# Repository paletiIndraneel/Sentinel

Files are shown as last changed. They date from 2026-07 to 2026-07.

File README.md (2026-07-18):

# Sentinel v1.0 firmware

Sentinel continuously monitors three-phase AC voltage and true internet
availability. It is an ESP32-S3 PlatformIO/Arduino project designed for the
provided controller PCB: ADS1115, DS3231, 128x64 SSD1306 OLED, microSD, and an
optional SHT31.

## Features

- 1-second RMS windows for R, Y, and B phase measurements
- Phase loss, under-voltage, over-voltage, and phase-imbalance events
- Internet reachability test using asynchronous TCP to a public endpoint
- Automatic Wi-Fi recovery without blocking `loop()`
- DS3231 ISO-8601 timestamps
- `events.csv` and `readings.csv` on a FAT32 microSD card
- OLED current voltage, connectivity, and fault status

## Project layout

```text
include/    Public module interfaces and configuration
src/        Module implementations and application composition root
lib/        Reserved for local libraries
docs/       Reserved for commissioning and operating documentation
hardware/   Reserved for released hardware assets
```

## Configure and flash

1. Install PlatformIO and open this directory.
2. Set `WIFI_SSID` and `WIFI_PASSWORD` in [include/config.h](include/config.h).
3. Verify `PHASE_SCALE`, phase-loss, under/over-voltage and imbalance limits
   against the installation requirements. Each ZMPT101B channel must be
   calibrated with an isolated, trusted reference meter.
4. Insert a FAT32 microSD card and upload:

   ```powershell
   pio run --target upload
   pio device monitor --baud 115200
   ```

## Connectivity behavior

The device distinguishes internet availability from mere association with a
Wi-Fi access point. It makes a non-blocking HTTP request to `1.1.1.1` every
minute. A 2xx response marks the internet `ONLINE`; connection failure or a
timeout marks it `OFFLINE`. Wi-Fi retry timing and endpoint configuration are
in `config.h`. No router monitoring, cloud connection, MQTT, OTA, dashboard,
or mobile functionality is included.

## Pin map

| Function | ESP32-S3 GPIO |
| --- | ---: |
| Status LED / Wi-Fi LED | 4 / 5 |
| I2C SDA / SCL | 8 / 9 |
| microSD CS / MOSI / SCK / MISO | 10 / 11 / 12 / 13 |

## Safety

This product interfaces with mains voltage. Commission only with suitable
isolation, enclosure, fusing and a qualified person. Default calibration is
`1.0` and is not a valid mains-voltage reading.

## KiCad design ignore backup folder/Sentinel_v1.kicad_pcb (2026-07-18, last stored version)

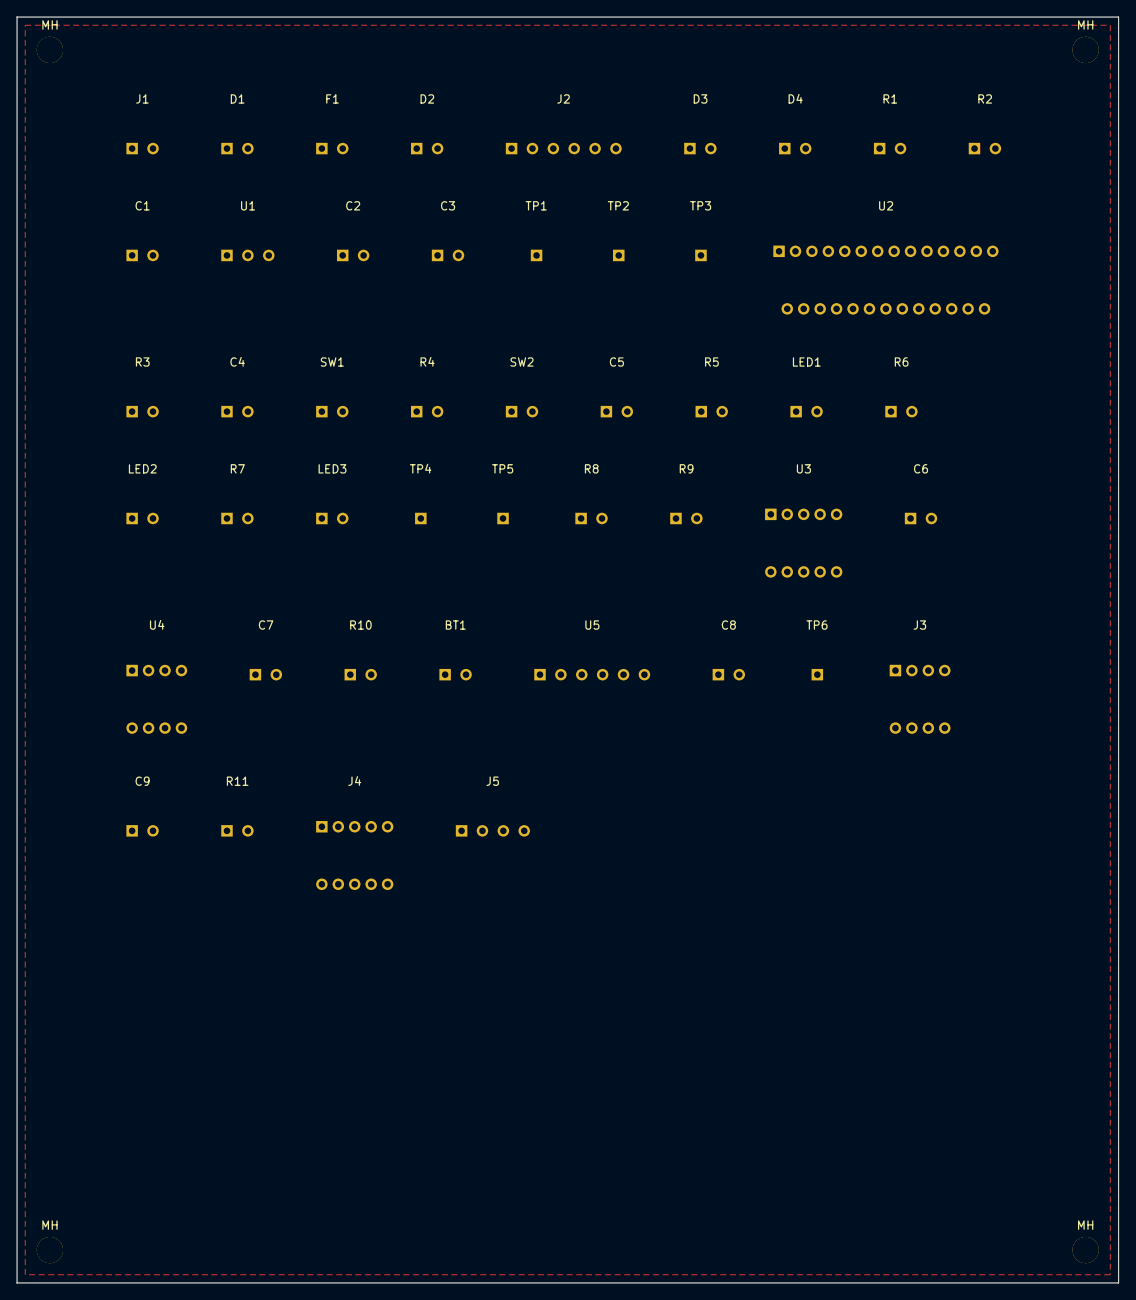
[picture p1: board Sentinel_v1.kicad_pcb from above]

Board: 2 copper layers, 134.0 x 154.0 mm, 51 parts (0 on the bottom side), 38 nets, no tracks yet.

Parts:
BT1: CR2032; BatteryHolder_Keystone_3034_1x20mm
C1, C2: 10uF; C_0603_1608Metric
C3, C4: 1uF; C_0603_1608Metric
C5, C6, C7, C8, C9: 0.1uF; C_0603_1608Metric
D1, D2, D3: SS34; D_SOD-123
D4: SMBJ5.0A; D_SOD-123
F1: MF-R500; Fuse_1210_3225Metric
J1: 5V_UPS_IN; TerminalBlock_bornier-2_P5.08mm
J2: USB-C; USB_C_Receptacle_HRO_TYPE-C-31-M-12
J3: MicroSD; microSD_HC_Molex-104031-0811
J4: EXP_HDR; PinHeader_2x05_P2.54mm_Vertical
J5: J_SENSOR; JST_XH_B4B-XH-A_1x04_P2.50mm_Vertical
LED1: STATUS; LED_0603_1608Metric
LED2: WIFI; LED_0603_1608Metric
LED3: PWR; LED_0603_1608Metric
MH: M3; MountingHole_3.2mm_M3
MH#2, MH#3, MH#4: M3; MountingHole_3.2mm_M3
R1, R2: 5.1k; R_0603_1608Metric
R3, R4, R10, R11: 10k; R_0603_1608Metric
R5, R6, R7: 330R; R_0603_1608Metric
R8, R9: 4.7k; R_0603_1608Metric
SW1: SW_RESET; SW_SPST_TL3342
SW2: SW_BOOT; SW_SPST_TL3342
TP1: TP_5V; TestPoint_Pad_1.5x1.5mm
TP2: TP_3V3; TestPoint_Pad_1.5x1.5mm
TP3: TP_GND; TestPoint_Pad_1.5x1.5mm
TP4: TP_SDA; TestPoint_Pad_1.5x1.5mm
TP5: TP_SCL; TestPoint_Pad_1.5x1.5mm
TP6: TP_A3_RSV; TestPoint_Pad_1.5x1.5mm
U1: AMS1117-3.3; SOT-223-3_TabPin2
U2: ESP32-S3-WROOM-1; ESP32-S2-MINI-1
U3: ADS1115; MSOP-10_3x3mm_P0.5mm
U4: DS3231; SOIC-16W_7.5x10.3mm_P1.27mm
U5: SHT31; DFN-8-1EP_2.5x2.5mm_P0.5mm_EP1.2x1.6mm

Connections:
3V3: C2.1, C3.1, C5.1, C6.1, C7.1, C8.1, C9.1, J3.3, J4.1, R3.1, R4.1, R7.1, R8.1, R9.1, R10.1, R11.1, TP2.1, U1.3, U2.1, U3.1, U4.1, U5.1
5V_A: D2.1, F1.2
5V_UPS_IN: D1.1, J1.1
5V_UPS_PROT: D1.2, F1.1
ADC_A3_RSV: TP6.1, U3.10
ADS_ALRT: U2.7, U3.6
BOOT: R4.2, SW2.1, U2.4
EN: C4.1, R3.2, SW1.1, U2.3
EXP_IO15: J4.3, U2.18
EXP_IO16: J4.4, U2.19
EXP_IO17: J4.5, U2.20
EXP_IO18: J4.6, U2.21
EXP_IO21: J4.7, U2.22
EXP_IO47: J4.8, U2.23
EXP_IO48: J4.9, U2.24
GND: BT1.2, C1.2, C2.2, C3.2, C4.2, C5.2, C6.2, C7.2, C8.2, C9.2, D4.2, J1.2, J2.2, J3.5, J3.8, J4.2, J4.10, J5.4, LED1.2, LED2.2, LED3.2, R1.2, R2.2, SW1.2, SW2.2, TP3.1, U1.2, U2.2, U2.25, U2.26, U2.27, U3.2, U3.5, U4.2, U5.2, U5.5
PHASE_B_ADC: J5.3, U3.9
PHASE_R_ADC: J5.1, U3.7
PHASE_Y_ADC: J5.2, U3.8
PWR_LED_A: LED3.1, R7.2
RTC_RST: R10.2, U4.7
SCL: R9.2, TP5.1, U2.9, U3.3, U4.4, U5.4
SDA: R8.2, TP4.1, U2.8, U3.4, U4.3, U5.3
SD_CS: J3.1, R11.2, U2.10
SD_MISO: J3.6, U2.13
SD_MOSI: J3.2, U2.11
SD_SCK: J3.4, U2.12
STATUS_GPIO: R5.1, U2.5
STATUS_LED_A: LED1.1, R5.2
USB_CC1: J2.5, R1.1
USB_CC2: J2.6, R2.1
USB_DM: J2.4, U2.14
USB_DP: J2.3, U2.15
VBAT: BT1.1, U4.8
VBUS_USB: D3.1, J2.1
VCC_5V: C1.1, D2.2, D3.2, D4.1, TP1.1, U1.1
WIFI_GPIO: R6.1, U2.6
WIFI_LED_A: LED2.1, R6.2

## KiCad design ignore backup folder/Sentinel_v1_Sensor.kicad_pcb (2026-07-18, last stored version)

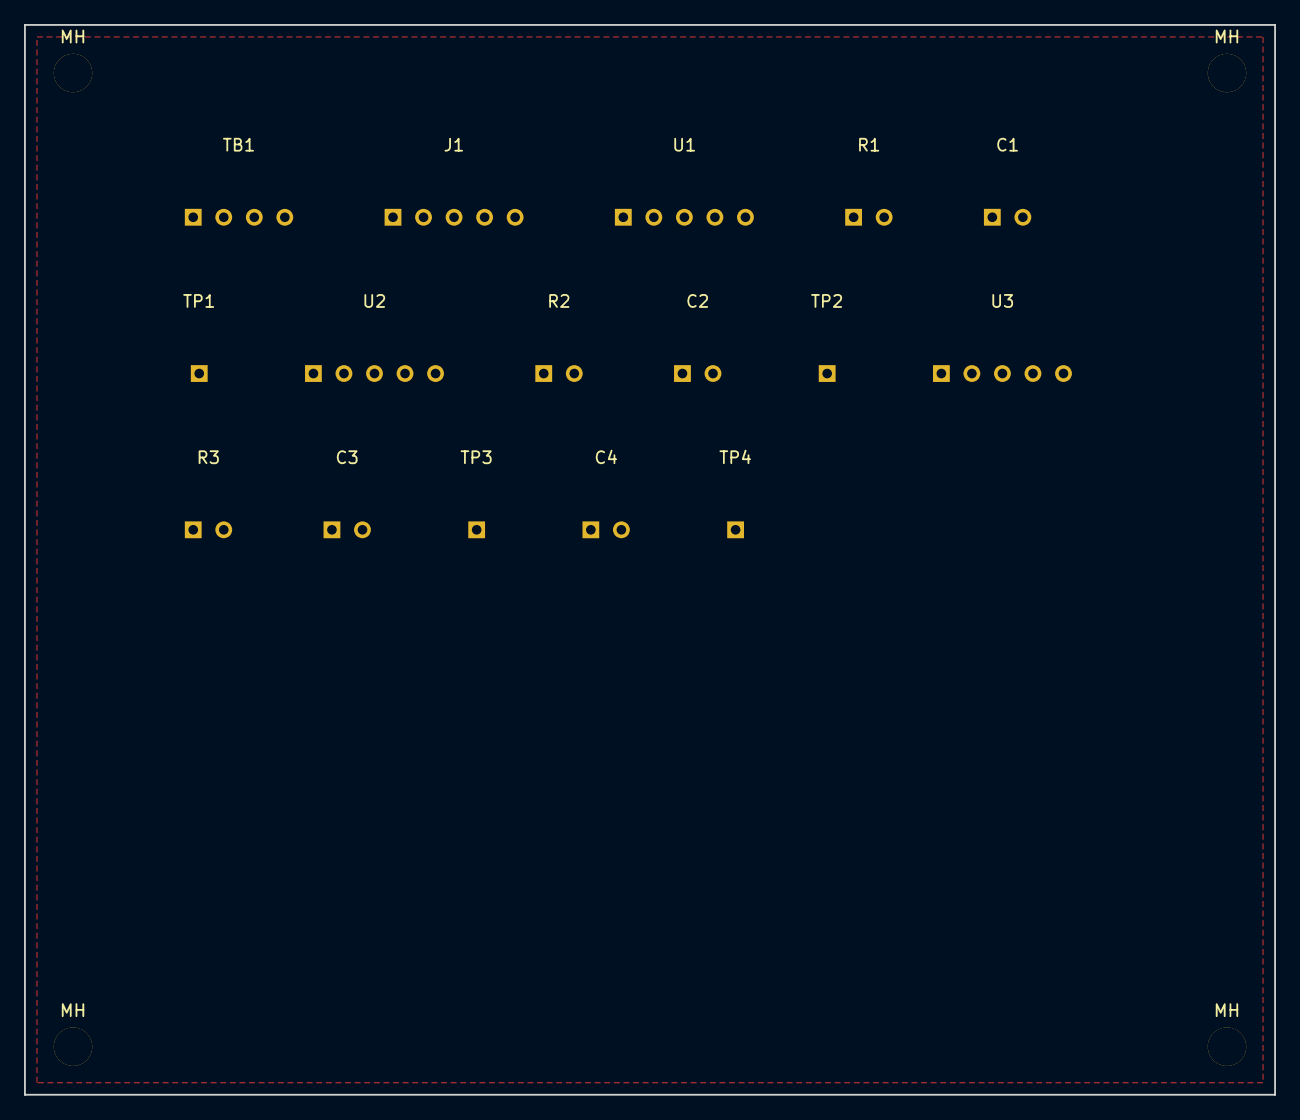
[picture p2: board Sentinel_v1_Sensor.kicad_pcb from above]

Board: 2 copper layers, 104.0 x 89.0 mm, 20 parts (0 on the bottom side), 12 nets, no tracks yet.

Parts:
C1, C2, C3: 100nF; C_0603_1608Metric
C4: 10uF; C_0603_1608Metric
J1: J_CTRL; JST_XH_B5B-XH-A_1x05_P2.50mm_Vertical
MH: M3; MountingHole_3.2mm_M3
MH#2, MH#3, MH#4: M3; MountingHole_3.2mm_M3
R1, R2, R3: 1k; R_0603_1608Metric
TB1: MAINS; TerminalBlock_bornier-4_P5.08mm
TP1: TP_R; TestPoint_Pad_1.5x1.5mm
TP2: TP_Y; TestPoint_Pad_1.5x1.5mm
TP3: TP_B; TestPoint_Pad_1.5x1.5mm
TP4: TP_GND; TestPoint_Pad_1.5x1.5mm
U1: ZMPT-R; ZMPT101B_Module
U2: ZMPT-Y; ZMPT101B_Module
U3: ZMPT-B; ZMPT101B_Module

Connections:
MAINS_B: TB1.3, U3.1
MAINS_N: TB1.4, U1.2, U2.2, U3.2
MAINS_R: TB1.1, U1.1
MAINS_Y: TB1.2, U2.1
OUT_B: C3.1, J1.5, R3.2, TP3.1
OUT_R: C1.1, J1.3, R1.2, TP1.1
OUT_Y: C2.1, J1.4, R2.2, TP2.1
SNS_5V: C4.1, J1.1, U1.3, U2.3, U3.3
SNS_GND: C1.2, C2.2, C3.2, C4.2, J1.2, TP4.1, U1.4, U2.4, U3.4
ZMPT_B_RAW: R3.1, U3.5
ZMPT_R_RAW: R1.1, U1.5
ZMPT_Y_RAW: R2.1, U2.5

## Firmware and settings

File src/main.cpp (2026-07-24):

#include <Arduino.h>
#include <Wire.h>
#include <SPI.h>
#include <WiFi.h>

#include "config.h"
#include "DisplayManager.h"
#include "EnvironmentMonitor.h"
#include "NotificationManager.h"
#include "EventDetector.h"
#include "InternetMonitor.h"
#include "TimeManager.h"
#include "Logger.h"
#include "RTCManager.h"
#include "VoltageMonitor.h"
#include "TelegramBot.h"

namespace sentinel {

class SentinelApp {
 public:
  void begin();
  void update();
  

 private:
  void logEvents(const EventBatch& events);
  void updateTrafficLights();
bool timeSyncNotified_ = false;
  VoltageMonitor voltage_;
  EventDetector events_;
  InternetMonitor internet_;
  NotificationManager notification_;
  TimeManager time_;
  RTCManager rtc_;
  Logger logger_;
  DisplayManager display_;
  EnvironmentMonitor environment_;
  VoltageSnapshot latestVoltage_;
  TelegramBot telegram_;
  bool telegramBootMessageSent_ = false;
  uint32_t lastReadingLogMs_ = 0;
  int8_t trafficState_ = -1;
};

void SentinelApp::begin() {
  Serial.begin(115200);
  delay(1000);
  Serial.println("Boot 1");
  Wire.begin(config::pin::I2C_SDA, config::pin::I2C_SCL);
  time_.begin();
  notification_.begin(&time_);
  notification_.info("Sentinel booting...");
  internet_.setDateCallback(
    [this](const String& date)
    {
      if (time_.setFromHttpDate(date))
        {
            if (!timeSyncNotified_)
            {
          notification_.success("system Clock synchronized");
          timeSyncNotified_ = true;
            }
        }else{
          notification_.warning("Failed to synchronize system time.");
        }
    }
  );
  internet_.begin();
  notification_.info("Wi-Fi connection manager ready.");
  if (telegram_.begin()){
    notification_.success("Telegram initialized.");
  }else{
    notification_.warning("Telegram initialization failed.");
  }
  notification_.success("Sentinel boot complete");
  pinMode(config::pin::TRAFFIC_RED, OUTPUT);
  pinMode(config::pin::TRAFFIC_YELLOW, OUTPUT);
  pinMode(config::pin::TRAFFIC_GREEN, OUTPUT);
  pinMode(config::pin::WIFI_LED, OUTPUT);
  pinMode(config::pin::STATUS_LED, OUTPUT);
 /* Serial.print("[initial Time] ");
  Serial.println(time_.getTimestamp());*/
  //Serial.println("Boot 2");

  // Disabled modules
  // voltage_.begin(Wire);
  // rtc_.begin(Wire);
  // display_.begin(Wire);
  // environment_.begin(Wire);
  // logger_.begin(SPI, config::pin::SD_CS);
  //Serial.println("Boot 3");
}

void SentinelApp::logEvents(const EventBatch& events) {
  // Logger disabled
}

void SentinelApp::updateTrafficLights() {
  const int8_t state =
      internet_.available() ? 2 :
      (WiFi.status() == WL_CONNECTED ? 1 : 0);

  if (state == trafficState_)
    return;
  trafficState_ = state;
  digitalWrite(config::pin::TRAFFIC_RED, state == 0 ? HIGH : LOW);
  digitalWrite(config::pin::TRAFFIC_YELLOW, state == 1 ? HIGH : LOW);
  digitalWrite(config::pin::TRAFFIC_GREEN, state == 2 ? HIGH : LOW);
}

void SentinelApp::update() {
  const uint32_t now = millis();

  // Internet monitor
  internet_.update(now);
  notification_.processQueue(telegram_,internet_.available());
  if (internet_.takeStatusChanged())
{
    if (internet_.isInternetAvailable())
    {
      notification_.success("Internet available.");
      if (!telegramBootMessageSent_){
        notification_.info(internet_.getConnectionInfo());
        notification_.success("🚀 Sentinel boot complete.");
        telegramBootMessageSent_ = true;
      }
    }
    else
    {
        notification_.warning("Internet unavailable.");
    }
}

  // Wi-Fi LED
  digitalWrite(
      config::pin::WIFI_LED,
      internet_.available() ? HIGH : LOW);

  // Traffic LEDs
  updateTrafficLights();

  // Everything below is disabled for Sentinel v1.0

  /*
  if (internet_.takeStatusChanged())
      logger_.logEvent(
          rtc_.timestamp(),
          {internet_.available()
               ? EventCode::InternetAvailable
               : EventCode::InternetUnavailable});

  voltage_.update(now);
  environment_.update(now);

  if (voltage_.hasNewSnapshot()) {
      latestVoltage_ = voltage_.snapshot();

      logEvents(events_.evaluate(latestVoltage_));

      digitalWrite(
          config::pin::STATUS_LED,
          !digitalRead(config::pin::STATUS_LED));
  }

  display_.update(
      now,
      latestVoltage_,
      internet_.available());

  if (latestVoltage_.valid &&
      now - lastReadingLogMs_ >=
          config::READING_LOG_INTERVAL_MS) {

      lastReadingLogMs_ = now;

      logger_.logReading(
          rtc_.timestamp(),
          latestVoltage_,
          environment_.reading(),
          internet_.available());
  }
  */
}

}  // namespace sentinel

sentinel::SentinelApp app;

void setup() {
  app.begin();
}

void loop() {
  app.update();
}

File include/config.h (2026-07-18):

#pragma once

#include <Arduino.h>

namespace sentinel::config {
// Keep credentials out of source control in a private config override.
#if __has_include("config_private.h")
#include "config_private.h"
#else
constexpr char WIFI_SSID[] = "CHANGE_ME";
constexpr char WIFI_PASSWORD[] = "CHANGE_ME";
#endif

// Public HTTP endpoint used only to verify internet reachability. It bypasses
// DNS deliberately, so a successful result proves routing beyond the LAN.
  
constexpr char INTERNET_TEST_HOST[] = "www.google.com";
constexpr uint16_t INTERNET_TEST_PORT = 80;

namespace pin {
constexpr uint8_t STATUS_LED = 4;
constexpr uint8_t WIFI_LED = 5;
constexpr uint8_t TRAFFIC_RED = 25;
constexpr uint8_t TRAFFIC_YELLOW = 26;
constexpr uint8_t TRAFFIC_GREEN = 27;
constexpr uint8_t I2C_SDA = 21;
constexpr uint8_t I2C_SCL = 22;
constexpr uint8_t SD_CS = 10;
constexpr uint8_t SD_MOSI = 11;
constexpr uint8_t SD_SCK = 12;
constexpr uint8_t SD_MISO = 13;
}  // namespace pin

constexpr uint32_t VOLTAGE_SAMPLE_INTERVAL_MS = 4;
constexpr uint32_t VOLTAGE_WINDOW_MS = 1000;
constexpr uint32_t READING_LOG_INTERVAL_MS = 60000;
constexpr uint32_t DISPLAY_INTERVAL_MS = 500;
constexpr uint32_t ENVIRONMENT_INTERVAL_MS = 5000;
constexpr uint32_t WIFI_CONNECT_TIMEOUT_MS = 15000;
constexpr uint32_t WIFI_RETRY_INTERVAL_MS = 30000;
constexpr uint32_t INTERNET_TEST_INTERVAL_MS = 60000;
constexpr uint32_t INTERNET_TEST_TIMEOUT_MS = 7000;

// Calibrate each channel with an isolated, trusted reference meter before use.
constexpr float PHASE_SCALE[] = {1.0F, 1.0F, 1.0F};
constexpr float PHASE_LOSS_V = 80.0F;
constexpr float UNDER_VOLTAGE_V = 180.0F;
constexpr float OVER_VOLTAGE_V = 260.0F;
constexpr float MAX_IMBALANCE_PERCENT = 5.0F;
}  // namespace sentinel::config
